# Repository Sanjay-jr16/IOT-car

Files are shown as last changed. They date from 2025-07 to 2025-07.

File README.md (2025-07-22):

# IOT-car
On-board diagnostics (OBD) is an automotive term referring to a vehicle's self-diagnostic and reporting capability. Up till now, OBD has evolved to OBD-II standard with 16 pins interface. 5 signaling protocols are permitted in the OBD-II interface, being SAE J1850 PWM, SAE J1850 VPW, ISO 9141-2, ISO 14230 KWP2000, and ISO 15765 CAN. To simply the design, this PCB only supports Controller Area Network (CAN) protocol.

The communication between an Arduino board and a vehicle is realized by two chips. MCP2551 is used as the interface between a CAN physical layer and a CAN protocol controller. STN1110 is a multiprotocol OBD to UART interpreter that supports all 5 protocols. Here we only use its CAN protocol translation functionality. The schematics of the connection is shown in the attachment.

Though both chip datasheets provide sample circuit schematics, It is worth noting that selection of the capacitors for the crystal is critical. Differential crystal may have different cap loading. Selecting wrong cap values will result in different oscillation frequency, and thus the communication between STN1110 and MCP2551 will fail. Adafruit has a good tutorial of how to calculate the value of the capacitors that attach to the crystal. A general rule of thumb is C1, C2 = 2*CL - 2*Cstray, where CL is the crystal's load capacitance, Cstray is the parasitic capacitance and is approximately 2-5 pF.

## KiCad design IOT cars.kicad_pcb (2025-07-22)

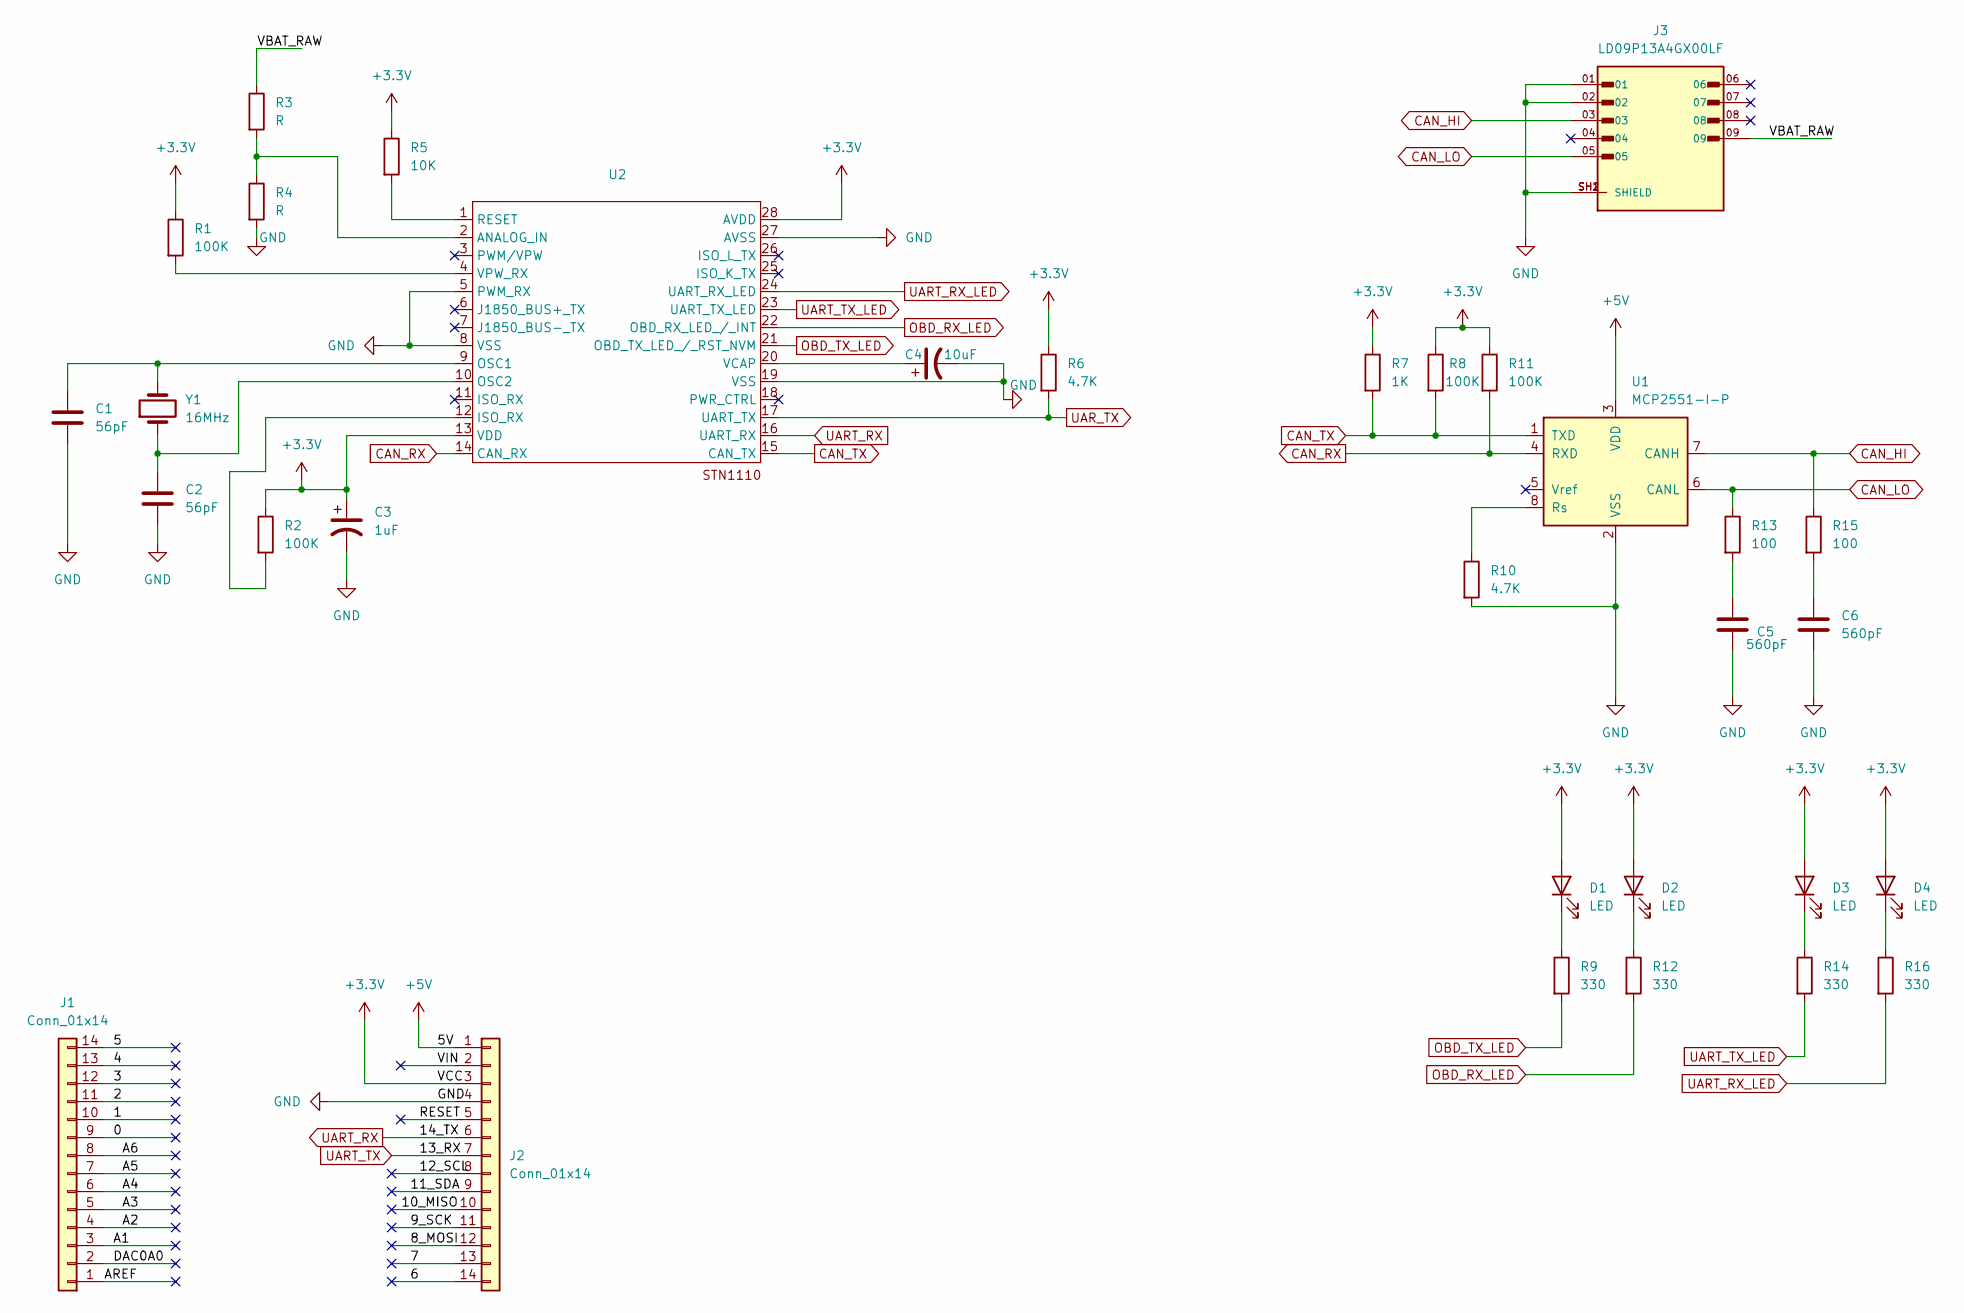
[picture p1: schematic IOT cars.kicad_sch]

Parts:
C1, C2: 56pF; C_Disc_D10.5mm_W5.0mm_P7.50mm
C3: 1uF; CP_Radial_D6.3mm_P2.50mm
C4: 10uF; CP_Radial_D5.0mm_P2.50mm
C5, C6: 560pF; C_Disc_D3.0mm_W2.0mm_P2.50mm
D1, D2, D3, D4: LED; LED_D5.0mm
J1, J2: Conn_01x14; PinSocket_1x14_P1.00mm_Vertical
J3: LD09P13A4GX00LF; TE_1-84952-0_1x10-1MP_P1.0mm_Horizontal; PARTREV B; DigiKey_Part_Number 609-5183-ND
R1, R2, R8, R11: 100K; R_Axial_DIN0411_L9.9mm_D3.6mm_P20.32mm_Horizontal
R3, R4: R; R_Axial_DIN0207_L6.3mm_D2.5mm_P15.24mm_Horizontal
R5: 10K; R_Axial_DIN0614_L14.3mm_D5.7mm_P15.24mm_Horizontal
R6, R10: 4.7K; R_Axial_DIN0207_L6.3mm_D2.5mm_P7.62mm_Horizontal
R7: 1K; R_Axial_DIN0207_L6.3mm_D2.5mm_P7.62mm_Horizontal
R9, R12, R14, R16: 330; R_Axial_DIN0207_L6.3mm_D2.5mm_P7.62mm_Horizontal
R13, R15: 100; R_Axial_DIN0207_L6.3mm_D2.5mm_P7.62mm_Horizontal
U1: MCP2551-I-P; DIP-8_W7.62mm
U2: Untitled
Y1: 16MHz; Crystal_HC49-4H_Vertical

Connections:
+3.3V: C3.1, D1.2 (A), D2.2 (A), D3.2 (A), D4.2 (A), J2.3, R1.1, R2.1, R5.1, R6.1, R7.1, R8.1, R11.1, U2.13 (VDD), U2.28 (AVDD)
+5V: J2.1, U1.3 (VDD)
/0: J1.9
/1: J1.10
/2: J1.11
/3: J1.12
/4: J1.13
/5: J1.14
/6: J2.14
/7: J2.13
/8_MOSI: J2.12
/9_SCK: J2.11
/10_MISO: J2.10
/11_SDA: J2.9
/12_SCL: J2.8
/ A1: J1.3
/ AREF: J1.1
/A2: J1.4
/A3: J1.5
/A4: J1.6
/A5: J1.7
/A6: J1.8
/DAC0A0: J1.2
/RESET: J2.5
/VBAT_RAW: J3.09, R3.1
/VIN: J2.2
CAN_HI: J3.03, R15.1, U1.7 (CANH)
CAN_LO: J3.05, R13.1, U1.6 (CANL)
CAN_RX: R11.2, U1.4 (RXD), U2.14 (CAN_RX)
CAN_TX: R7.2, R8.2, U1.1 (TXD), U2.15 (CAN_TX)
GND: C1.2, C2.2, C3.2, C4.2, C5.2, C6.2, J2.4, J3.01, J3.02, J3.SH1 (SHIELD), J3.SH2 (SHIELD), R4.2, R10.2, U1.2 (VSS), U2.5 (PWM_RX), U2.8 (VSS), U2.19 (VSS), U2.27 (AVSS)
unnamed: C5.1, R13.2
unnamed: C6.1, R15.2
unnamed: D1.1 (K), R9.1
unnamed: D2.1 (K), R12.1
unnamed: D3.1 (K), R14.1
unnamed: D4.1 (K), R16.1
unnamed: R2.2, U2.12 (ISO_RX)
unnamed: R10.1, U1.8 (Rs)
unnamed: R3.2, R4.1, U2.2 (ANALOG_IN)
unnamed: C1.1, U2.9 (OSC1), Y1.2
unnamed: C2.1, U2.10 (OSC2), Y1.1
unnamed: R5.2, U2.1 (RESET)
unnamed: C4.1, U2.20 (VCAP)
unnamed: R1.2, U2.4 (VPW_RX)
OBD_RX_LED: R12.2, U2.22 (OBD_RX_LED_/_INT)
OBD_TX_LED: R9.2, U2.21 (OBD_TX_LED_/_RST_NVM)
UART_RX: J2.6, U2.16 (UART_RX)
UART_RX_LED: R16.2, U2.24 (UART_RX_LED)
UART_TX: J2.7
UART_TX_LED: R14.2, U2.23 (UART_TX_LED)
UAR_TX: R6.2, U2.17 (UART_TX)

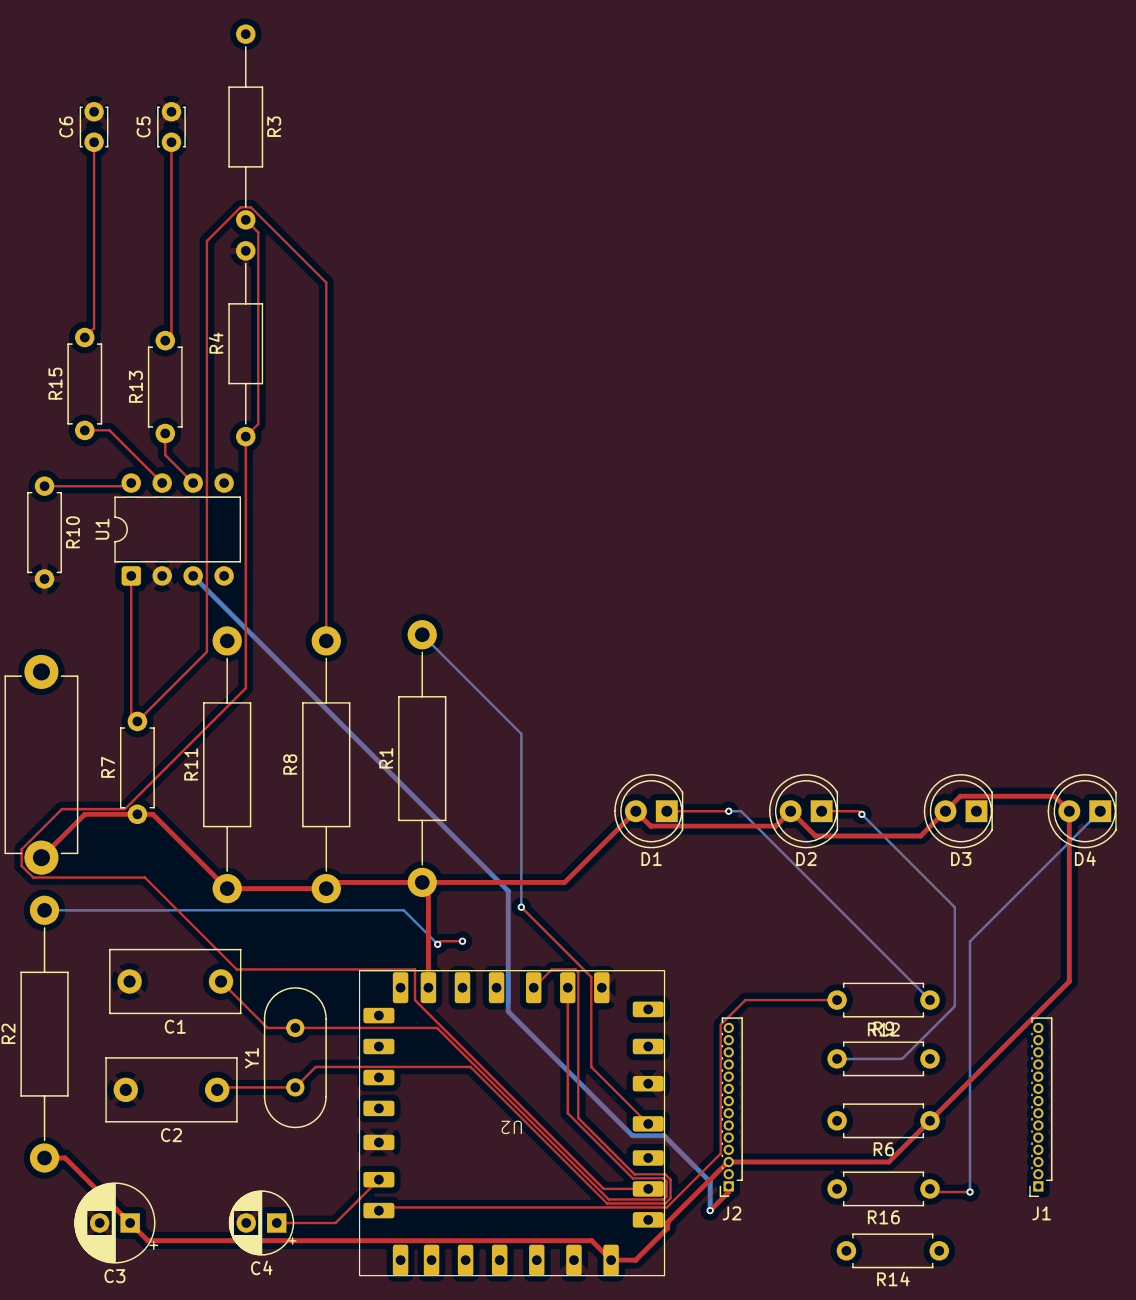
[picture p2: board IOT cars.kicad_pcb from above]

Board: 4 copper layers, 31 parts (0 on the bottom side), 27 nets.

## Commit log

2025-07-22 Schematic Daigram
    [IOT cars.kicad_sch]
2025-07-22 Gerber files
